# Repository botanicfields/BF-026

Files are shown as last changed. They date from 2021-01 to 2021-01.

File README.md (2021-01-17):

# HK322 Music Player

## メロディ IC HK322 HK326 基板キット

メロディ IC HK322 または HK326 の演奏を楽しめる組み立てキットです。プリント基板と部品のセットです。データシートの応用回路を実現できます。

単三乾電池 2 本を使用します。電池は付属しません。

モーターを接続できます。モーターは付属しません。

[組み立て例]

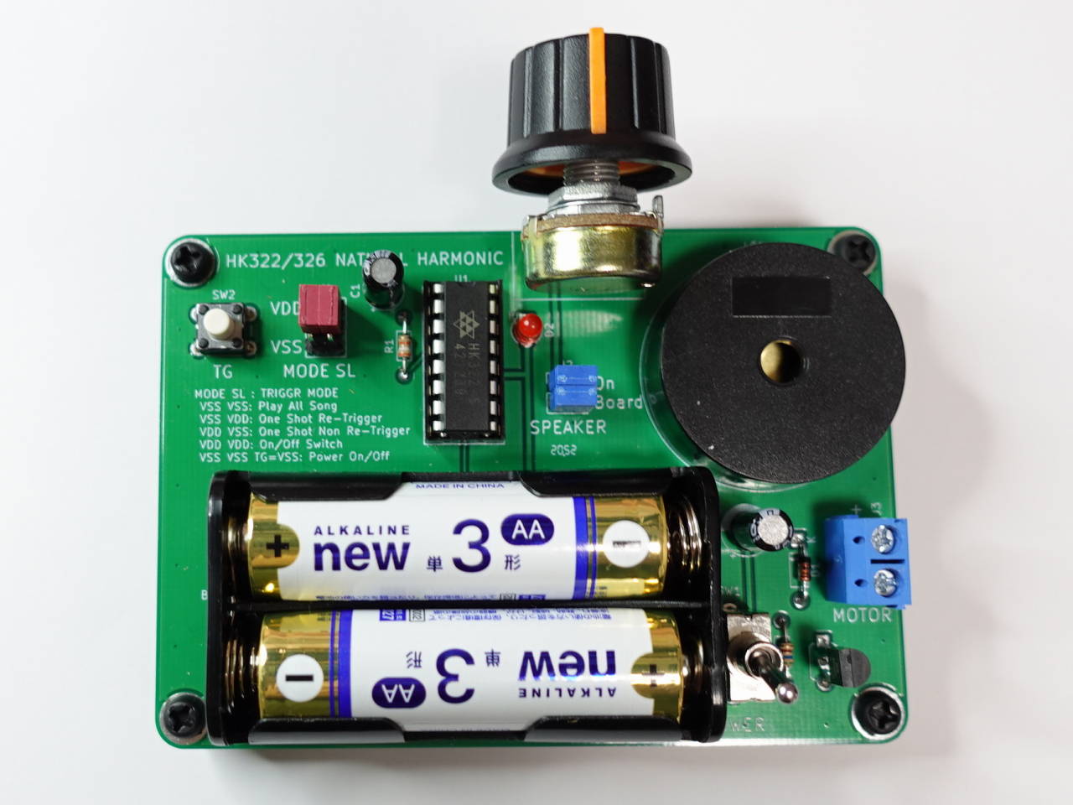
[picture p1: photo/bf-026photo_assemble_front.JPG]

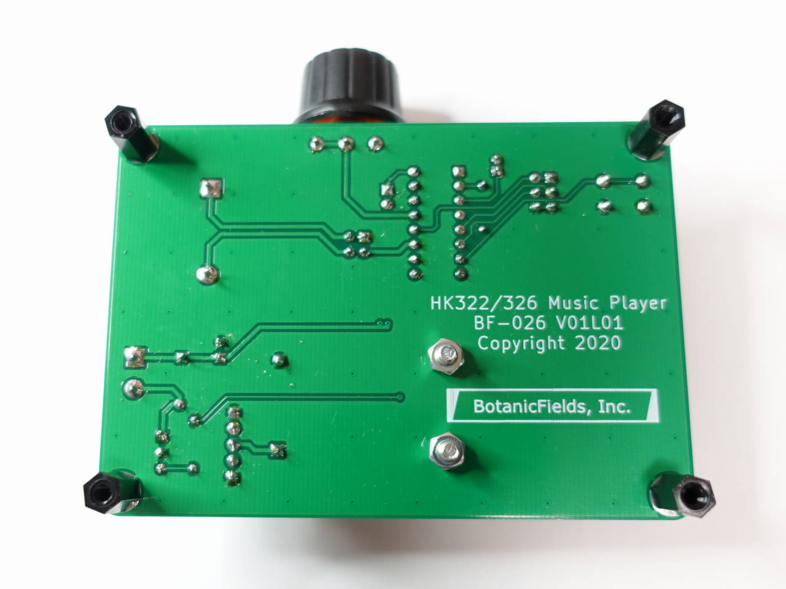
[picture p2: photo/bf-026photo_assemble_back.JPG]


## 1. 機能

- 基板上に小型スピーカーがあり、単体で演奏できます。
- 音量を調整できます。
- LED がテンポに合わせて点滅します。
- モーターの接続端子があり、演奏中に回せます。
- ボタン操作の動作モードを選べます。
- スピーカー出力をピンヘッダから外部に取り出せます。

[動作例 BF-026: HK322-6 Music Player (Speaker on Board)] https://youtu.be/cPjyi8aC4bo

## **※音量が、かなり小さいです。**

添付の圧電スピーカーを以下の部品に交換すると、音量や音質を改善できます。しかし基板上の**VR による音量調節**は、ほとんどできなくなります。

[基板取付用スピーカーユニット　ＵＧＳＭ３０Ｂ－８－０１]https://akizukidenshi.com/catalog/g/gP-09271/

[動作例 BF-026: HK-322-6 Music Player (Speaker External)] Https://youtu.be/JqZQZIhNCvg

プリント基板が両面スルーホールのため、一旦取り付けた部品を交換するのは難易度が高いです。特にスピーカーは構造が華奢で壊れやすいです。外付けで大きなスピーカーに接続する方が安全です。

## 2. 組み立て

組み立てには、はんだ付けが必要です。はんだ、はんだごて、ニッパー等が必要です。ターミナルブロックへの導線の接続には、ドライバー等が必要です。

背の低い部品からプリント基板にはんだ付けするのがコツです。部品表の記号で部品を識別して取り付ける場所を確認してください。

ダイオードやトランジスタの向きに注意し、帯表示や外形を合わせてください。
LED にも極性があり、リード線の短い方がマイナスです。プリント基板上の K (Kathode) マークがマイナス側です。
電解コンデンサにも極性があり、リード線の短い方がマイナスです。

電池ホルダーのピンは、一旦まっすぐにしてから取り付けてください。皿ネジとナットで位置決めしてから、ピンをはんだ付けします。

SPEAKER 表示のピンヘッダー (4p) に、ショートピン 2 本をプリント基板の長い方向に並べて挿します。外部スピーカー等を使用する場合は、ショートピンを取り外して IC に近い方のピン 2 本から信号を取り出します。

[キット内容]

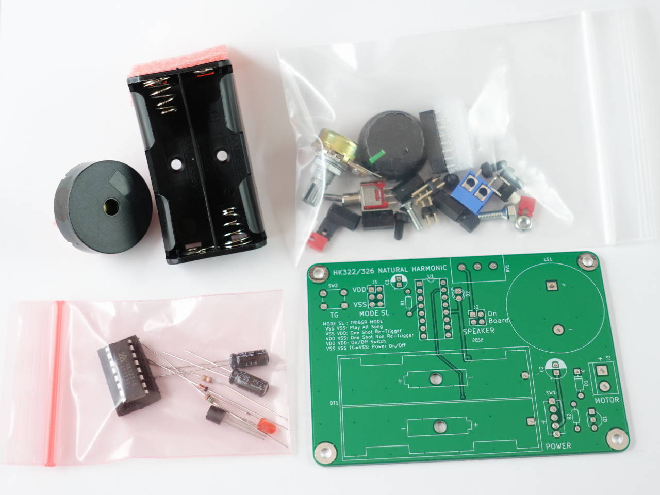
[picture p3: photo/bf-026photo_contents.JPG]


[プリント基板]

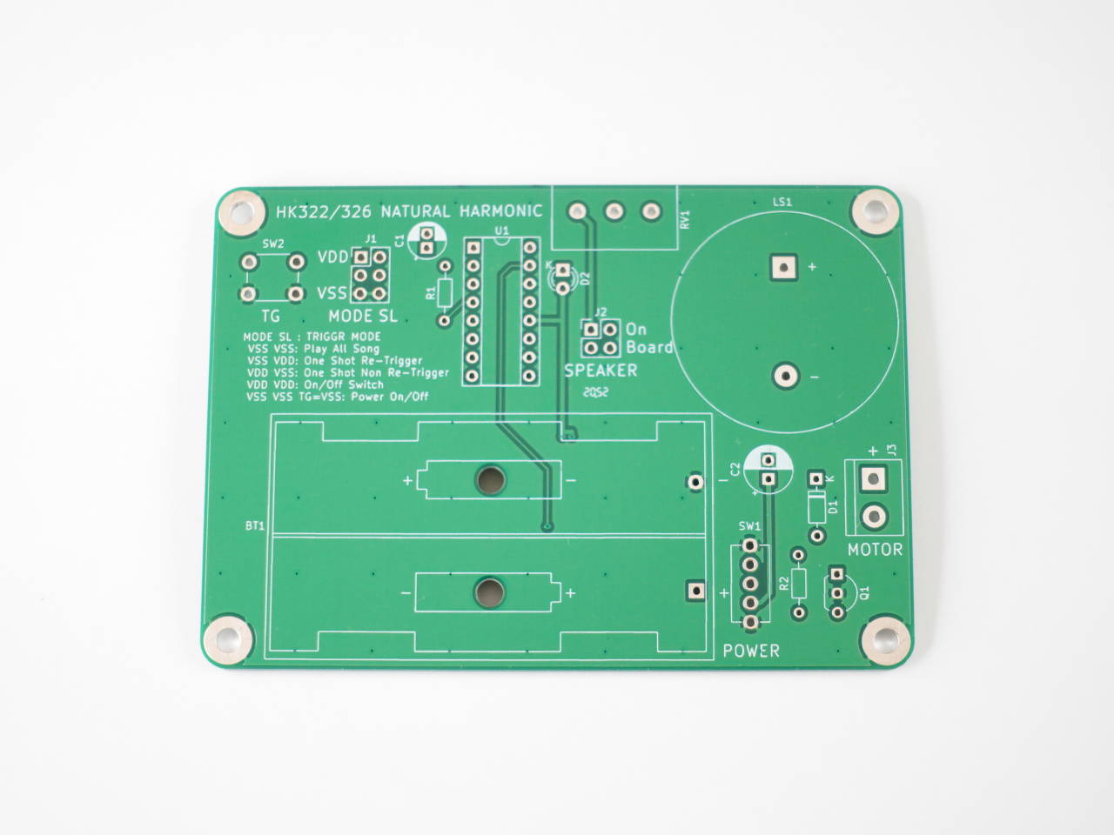
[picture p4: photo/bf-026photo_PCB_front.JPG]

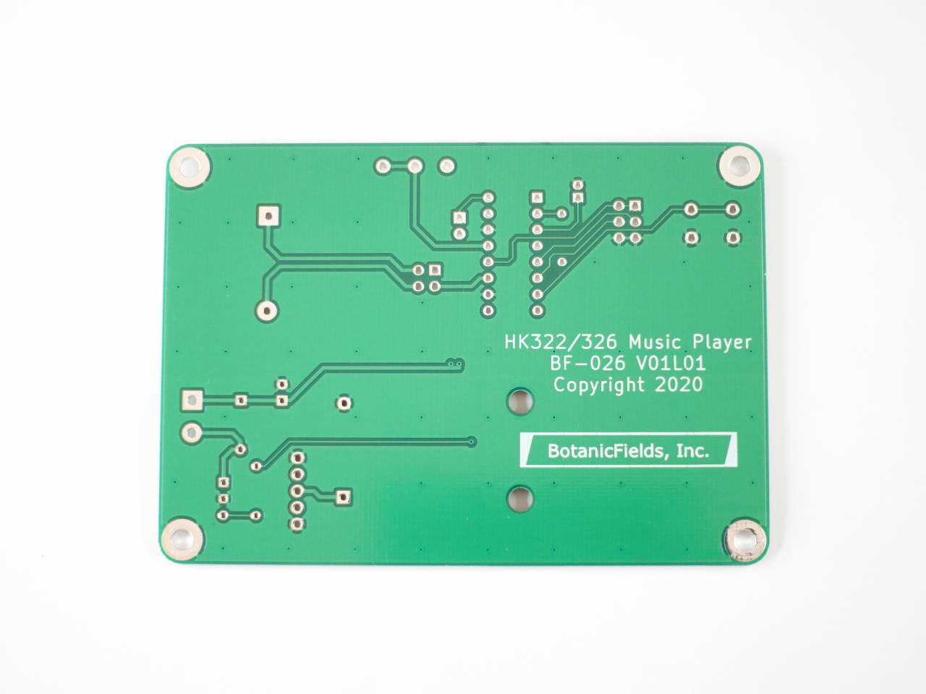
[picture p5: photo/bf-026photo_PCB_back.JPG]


## 3. 動作

動作モードは、ピンヘッダー (6p) に対してショートピン 2 本で設定します。

| MODE | SL | 動作モード | TG ボタンの動作 |
|:--:|:--:|:---|:---|
| VSS | VSS | Play All Songs　| 全曲を 1 回演奏します |
| VSS | VDD | One Shot Re-Trigger | 1 曲目を演奏します。曲の途中で TG ボタンを押すと次の曲に移ります |
| VDD | VSS | One Shot Non Re-Tregger　| 1 曲目を最後まで演奏します。演奏後 TG ボタンを押すと次の曲を最後まで演奏します |
| VDD | VDD | On/Off Switch　|  全曲を 1 回演奏します。演奏中に TG ボタンを押すと演奏を停止します |
| VSS | VSS | TG = VSS: Power On/Off　| TG を VSS と短絡しておくと、電源オンで全曲を 1 回演奏します |

## 4. 参考資料

メロディ IC の機能、動作の詳細、曲目の違いなどは、リンク先を参照ください。

- HK322, HK326 メーカー:

[Honsitak Electronics Co., Ltd.] https://www.honsitak-taiwan.com/products03.htm

- 小売：株式会社秋月電子通商

[HK322-1] https://akizukidenshi.com/catalog/g/gI-15483/

[HK322-3] https://akizukidenshi.com/catalog/g/gI-15484/

[HK322-6] https://akizukidenshi.com/catalog/g/gI-15485/

[HK326-2] https://akizukidenshi.com/catalog/g/gI-15486/

## 5. 提供元

[twitter] https://twitter.com/botanicfields

[facebook] https://www.facebook.com/botanicfields

[GitHub] https://github.com/botanicfields

[Qiita] https://qiita.com/BotanicFields

[SwitchScience] https://www.switch-science.com/catalog/list/1084/

Copyright 2021 BotanicFields, Inc.

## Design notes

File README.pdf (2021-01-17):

README.md | 1/17/2021

# HK322 Music Player

## メロディ IC HK322 HK326 基板キット

メロディ IC HK322 または HK326 の演奏を楽しめる組み⽴てキットです。プリント基板と部品のセットで す。データシートの応⽤回路を実現できます。
単三乾電池 2 本を使⽤します。電池は付属しません。

モーターを接続できます。モーターは付属しません。
[組み⽴て例]

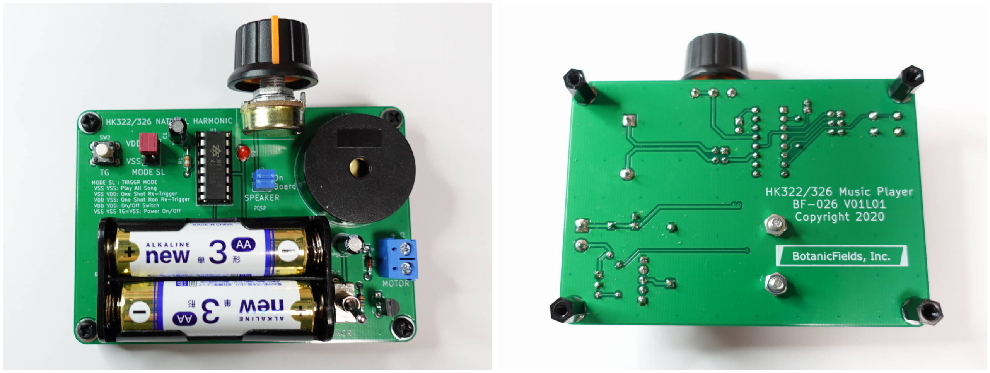
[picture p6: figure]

1. 機能

基板上に⼩型スピーカーがあり、単体で演奏できます。
⾳量を調整できます。
LED がテンポに合わせて点滅します。
モーターの接続端⼦があり、演奏中に回せます。
ボタン操作の動作モードを選べます。
スピーカー出⼒をピンヘッダから外部に取り出せます。

[動作例 BF-026: HK322-6 Music Player (Speaker on Board)] https://youtu.be/cPjyi8aC4bo

## ※⾳量が、かなり⼩さいです。

添付の圧電スピーカーを以下の部品に交換すると、⾳量や⾳質を改善できます。しかし基板上のVR による ⾳量調節は、ほとんどできなくなります。

[基板取付⽤スピーカーユニット ＵＧＳＭ３０Ｂ－８－０１]https://akizukidenshi.com/catalog/g/gP-09271/

[動作例 BF-026: HK-322-6 Music Player (Speaker External)] Https://youtu.be/JqZQZIhNCvg

プリント基板が両⾯スルーホールのため、⼀旦取り付けた部品を交換するのは難易度が⾼いです。特にスピ ーカーは構造が華奢で壊れやすいです。外付けで⼤きなスピーカーに接続する⽅が安全です。

## 2. 組み⽴て

組み⽴てには、はんだ付けが必要です。はんだ、はんだごて、ニッパー等が必要です。ターミナルブロック への導線の接続には、ドライバー等が必要です。
背の低い部品からプリント基板にはんだ付けするのがコツです。部品表の記号で部品を識別して取り付ける 場所を確認してください。
ダイオードやトランジスタの向きに注意し、帯表⽰や外形を合わせてください。 LED にも極性があり、リー ド線の短い⽅がマイナスです。プリント基板上の K (Kathode) マークがマイナス側です。 電解コンデンサに も極性があり、リード線の短い⽅がマイナスです。
電池ホルダーのピンは、⼀旦まっすぐにしてから取り付けてください。⽫ネジとナットで位置決めしてか ら、ピンをはんだ付けします。
SPEAKER 表⽰のピンヘッダー (4p) に、ショートピン 2 本をプリント基板の⻑い⽅向に並べて挿します。外部 スピーカー等を使⽤する場合は、ショートピンを取り外して IC に近い⽅のピン 2 本から信号を取り出しま す。
[キット内容]


[プリント基板]

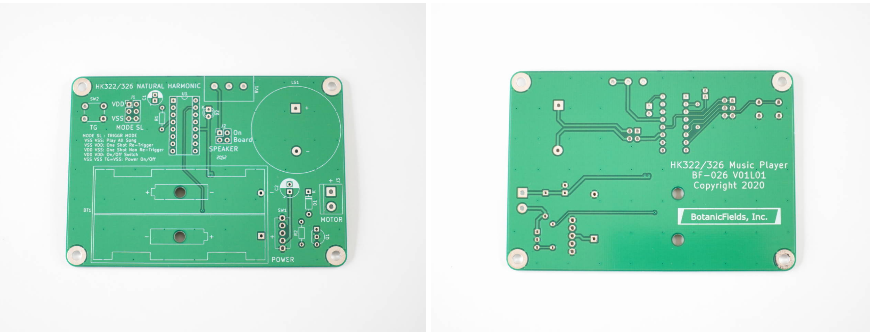
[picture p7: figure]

3. 動作

動作モードは、ピンヘッダー (6p) に対してショートピン 2 本で設定します。

MODE | SL | 動作モード | TG ボタンの動作
VSS | VSS | Play All Songs | 全曲を 1 回演奏します
VSS | VDD | One Shot Re- Trigger | 1 曲⽬を演奏します。曲の途中で TG ボタンを押すと次の曲に移 ります
VDD | VSS | One Shot Non Re- Tregger | 1 曲⽬を最後まで演奏します。演奏後 TG ボタンを押すと次の曲 を最後まで演奏します
VDD | VDD On/Off Switch
| | | 全曲を 1 回演奏します。演奏中に TG ボタンを押すと演奏を停⽌ します
VSS | VSS | TG = VSS: Power On/Off | TG を VSS と短絡しておくと、電源オンで全曲を 1 回演奏します

## 4. 参考資料

メロディ IC の機能、動作の詳細、曲⽬の違いなどは、リンク先を参照ください。

HK322, HK326 メーカー:

[Honsitak Electronics Co., Ltd.] https://www.honsitak-taiwan.com/products03.htm

⼩売︓株式会社秋⽉電⼦通商

[HK322-1] https://akizukidenshi.com/catalog/g/gI-15483/

[HK322-3] https://akizukidenshi.com/catalog/g/gI-15484/

[HK322-6] https://akizukidenshi.com/catalog/g/gI-15485/

[HK326-2] https://akizukidenshi.com/catalog/g/gI-15486/

## 5. 提供元

[twitter] https://twitter.com/botanicfields

[facebook] https://www.facebook.com/botanicfields

[GitHub] https://github.com/botanicfields

[Qiita] https://qiita.com/BotanicFields

[SwitchScience] https://www.switch-science.com/catalog/list/1084/

Copyright 2021 BotanicFields, Inc.

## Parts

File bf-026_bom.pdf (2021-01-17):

Copyright 2021 BotanicFields, Inc.

部品表 BF-026 | V01 | (メーカー、型名、販売店、注文型名などは一例です。同等品を使用する場合があります) | 2021/1/16
No. | 記号 | 品名 | 値 | 数量 | メーカー | 型名 | 販売店 | 注文型名 | 注文型名の備考 | キットの備考
1 | U1 | メロディIC | - | 1 | Honsitak Electronics | HK322-1 HK322-3 HK322-6 HK326-2 | 秋月電子通商 | I-15483 I-15484 I-15485 I-15486 | 詳細は秋月電子通商のWebサイトを参照 ください | HK322-6のみ付属します
2 | Q1 | トランジスタPNP | - | 1 | UNISONIC TECHNOLOGIES | 8550SL-D-T92-K | 秋月電子通商 | I-10055 | 20個入
3 | D1 | ダイオード | - | 1 | On Semiconductor | 1N4148 | 秋月電子通商 | I-00941 | 50本入
4 | D2 | LED | - | 1 | OptoSupply | OSG8HA3Z74A | 秋月電子通商 | I-11637
5 | R1 | カーボン抵抗 1/6W | 39kΩ | 1 | SHIH HAO Electronics | RD16S 39K | 秋月電子通商 | R-16393 | 100本入
6 | R2 | カーボン抵抗 1/6W | 560Ω | 1 | SHIH HAO Electronics | RD16S 560E | 秋月電子通商 | R-16561 | 100本入
7 | C1 | 電解コンデンサ | 2.2μF | 1 | ルビコン | 50PK2R2MEFC5X11 | 秋月電子通商 | P-03171
8 | C2 | 電解コンデンサ | 100μF | 1 | ルビコン | 25PK100MEFC5X11 | 秋月電子通商 | P-03122
9 | LS1 | スピーカー | - | 1 | SPL (Hong Kong) Limited | PT10-301025APR | 秋月電子通商 | P-15361
10 | SW1 | トグルスイッチ | - | 1 | Cosland | 2MS1-T1-B4-VS2-Q-E-S | 秋月電子通商 | P-00300
11 | SW2 | タクトスイッチ | - | 1 | Cosland | TS-0606-F-N-RED TS-0606-F-N-BLK TS-0606-F-N-WHT TS-0606-F-N-BLU TS-0606-F-N-YLW TS-0606-F-N-GRN TS-0606-F-N-ORG TS-0606-F-N-BWN | 秋月電子通商 | P-03646 P-03647 P-03648 P-03649 P-03650 P-03651 P-03652 P-03653 | タクトスイッチ（赤色） タクトスイッチ（黒色） タクトスイッチ（白色） タクトスイッチ（水色） タクトスイッチ（黄色） タクトスイッチ（緑色） タクトスイッチ（オレンジ色） タクトスイッチ（茶色） | 色は選べません
12 | - | DIP-IC ソケット 16p | - | 1 | Neltron Industrial | 2227-16-03 | 秋月電子通商 | P-00007 | 10個入
13 | J3 | ターミナルブロック 2P | - | 1 | Alphaplus Connectors & Cables | TB111-2-2-U-1-1 TB111-2-2-E-1-1 | 秋月電子通商 | P-01306 P-02333 | 青色 緑色 | 色は選べません
14 | J1 | ピンヘッダー 2.54mm 2列 6p | - | 1 | 廣杉計器 | PSS-420256-03 | ヒロスギネット | PSS-420256-03 | 20個入/40個入
15 | J2 | ピンヘッダー 2.54mm 2列 4p | - | 1 | 廣杉計器 | PSS-420256-02 | ヒロスギネット | PSS-420256-02 | 20個入/40個入
16 | - | ショートピン 2.54mm | - | 4 | Useconn Electronics | MJ-254-6BK MJ-254-6R MJ-254-6W MJ-254-6BU MJ-254-6Y MJ-254-6G | 秋月電子通商 | P-03687 P-03688 P-03689 P-03690 P-03691 P-03692 | 黒色(25個入) 赤色(25個入) 白色(25個入) 青色(25個入) 黄色(25個入) 緑色(25個入) | 色は選べません
17 | BT1 | 電池ボックス 単三(AA) 2本 | - | 1 | COMFORTABLE ELECTRONIC | BH-321-2P24 | 秋月電子通商 | P-10197
18 | - | スペーサ M3 10mm | - | 4 | 廣杉計器 | ASN-310 | ヒロスギネット | ASN-310 | 20個入/40個入
19 | - | ネジ M3 6mm | - | 4 | 廣杉計器 | N-0306 | ヒロスギネット | N-0306 | 20個入/40個入
20 | - | 皿ネジ M3 8mm | | 2 | 廣杉計器 | FF-0306E | ヒロスギネット | FF-0306E | 40個入
21 | - | ナット M3 | | 2 | 廣杉計器 | FNT-03E | ヒロスギネット | FNT-03E | 40個入
22 | RV1 | 可変抵抗 | 50kΩ | 1 | Changzhou Kennon Electronics | WH148-1A-2 | aitendo | WH148-1A-2
23 | - | ツマミ | - | 1 | - | VOLD20H15 | aitendo | VOLD20H15 | 白・緑・オレンジ・青・赤 | 形や色は選べません
24 | - | プリント基板 | - | 1 | NextPCB | BF-026 | NextPCB | BF-026
25 | - | 乾電池 単三(AA) | - | 2 | Golden Power Industries | GLR6A | 秋月電子通商 | B-03256 | 4本入 | 付属しません
26 | - | スピーカー | - | 1 | UNIVERSAL(CHANGZHOU) ELECTRONICS | UGSM30B-8-01 | 秋月電子通商 | P-09271 | | 付属しません 基板上のVRで音量調節ができません
27 | - | モーター | - | 1 | Connaught Motor (Shenzhen) | RF300CV-11320-23.5M-R | 秋月電子通商 | P-13630 | | 付属しません

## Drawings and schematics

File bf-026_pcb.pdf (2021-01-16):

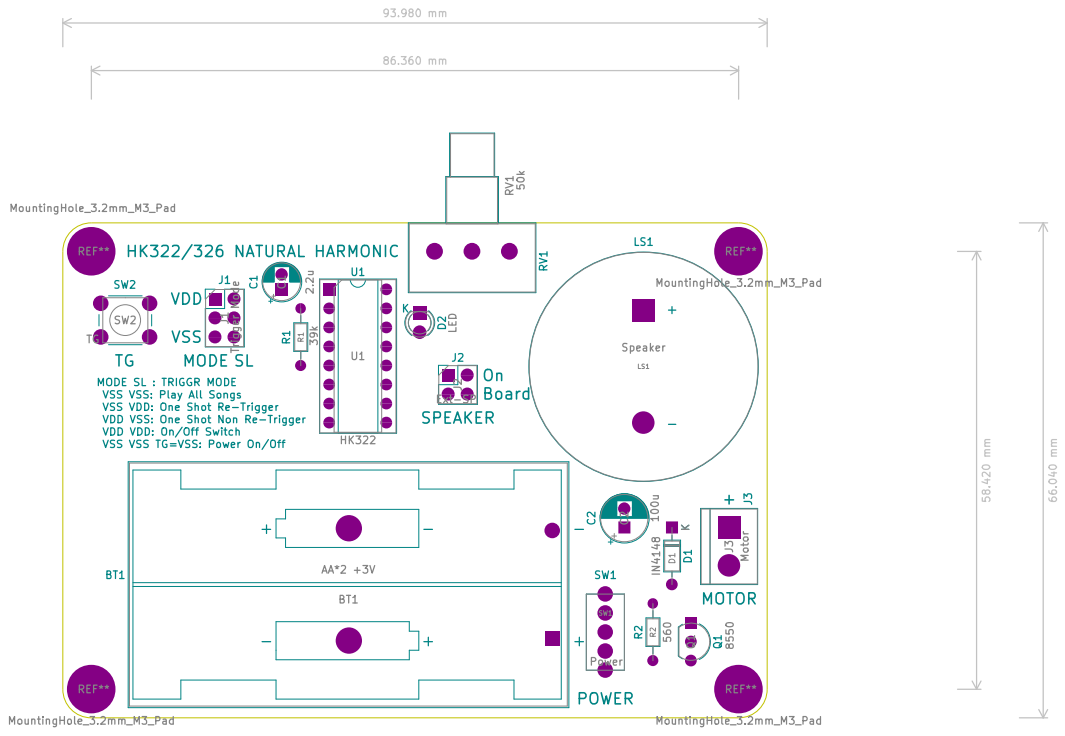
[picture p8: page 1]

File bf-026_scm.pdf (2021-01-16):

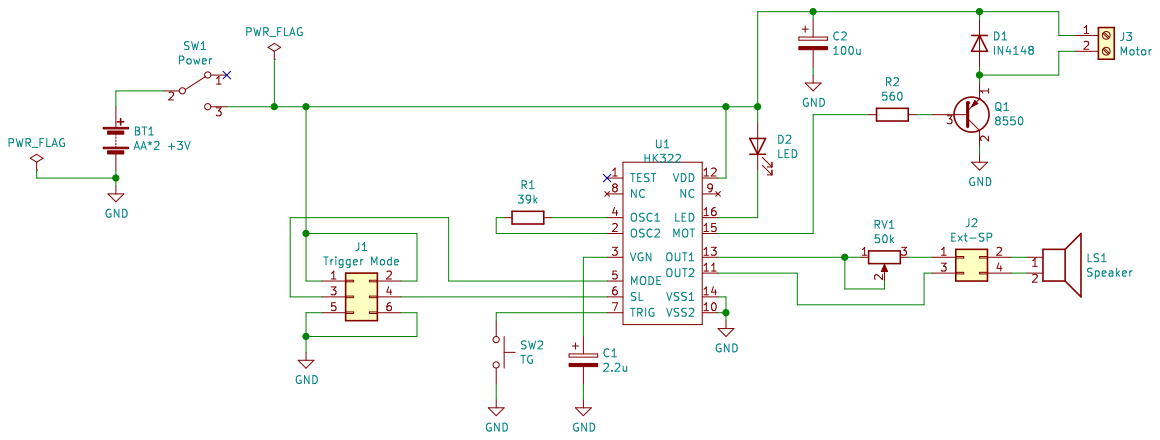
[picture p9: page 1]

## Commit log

2021-01-16 pdfs of pcb
    release version
2021-01-16 PCB data
    symbols, footprints
2021-01-16 gerber
    add gerber V01L02
    [bf-026-B_Cu.gbl, bf-026-B_Mask.gbs, bf-026-B_SilkS.gbo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]
